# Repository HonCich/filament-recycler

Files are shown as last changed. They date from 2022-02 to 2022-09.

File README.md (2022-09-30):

# filament-recyclator
 
## About project
 The goal of the work is design and implementation of a machine for production and recyclation of 3D printing material for FDM 3D printers (filament). The emphasis is put on the simplicity of the resulting device and the ease of its production process.

 I started working on this project at the end of summer 2021 with great help from Ing. Martin Ptáček. It started as my project for Středoškolská odborná činnost, which is science competetion held in the Czech Republic. After this competetion I decided to continue and further upgrade this machine.

 At this moment project contains working designs of filament extruder, filament puller, electronics board and software.

## 3D models
[Extruder 3D model](https://cad.onshape.com/documents/50d4ffc71355bbf60bf18542/w/1bb6894ef7bc64ec395a8974/e/ffa39023716e79eba0ffd74a)

[Gearbox 3D model](https://cad.onshape.com/documents/cd74832d7d2c633c7039baa6/w/958712d359a12f9b1e2d2bfe/e/a4a0fd0a7c25512e608e8250)

[Filament puller 3D model](https://cad.onshape.com/documents/47426692b6b663d8016df0e7/w/ed22a120c506776f4e319dcb/e/ad41a19a2c0e068ddb01ab12)

## Licence
* Contents of this repository except *software* folder are shared under [Attribution-NonCommercial-ShareAlike 4.0 International (CC BY-NC-SA 4.0)](https://creativecommons.org/licenses/by-nc-sa/4.0/) licence.
* Contents of *software* folder are shared under [GNU Lesser General Public License v3.0](https://www.gnu.org/licenses/lgpl-3.0.en.html) licence.

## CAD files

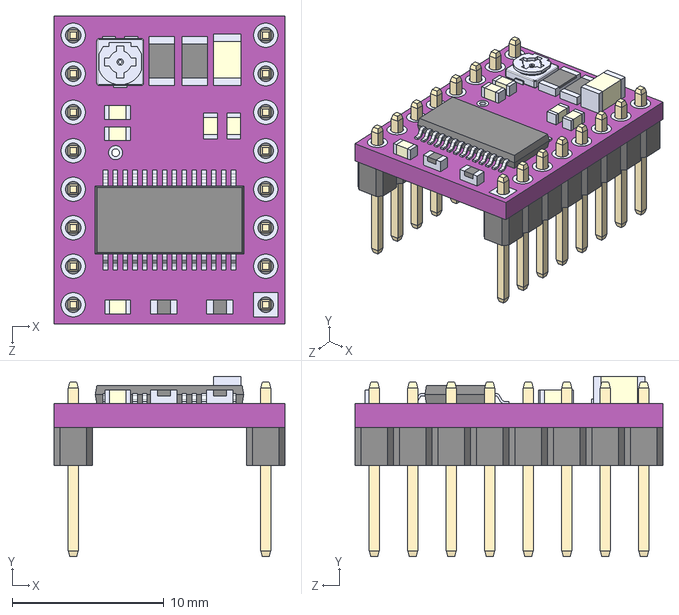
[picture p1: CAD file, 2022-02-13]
main_board/DRV8825 STEPPER MOTOR DRIVER CARRIER--3DModel-STEP-1.STEP
15.2 x 11.9 x 20.3 mm

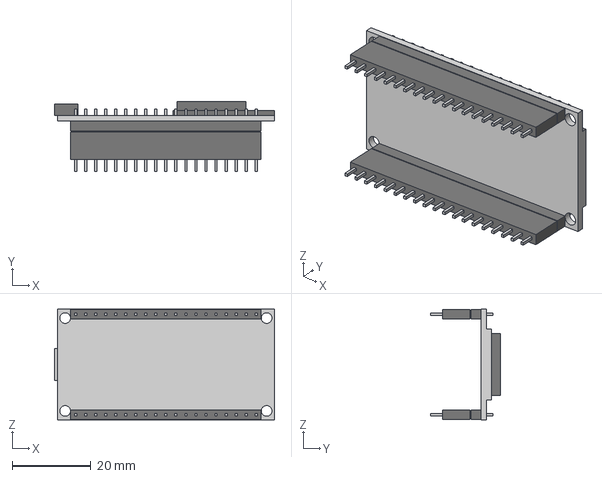
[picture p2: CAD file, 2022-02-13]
main_board/ESP32_DevKitC v2.step
55.7 x 17.6 x 28.0 mm

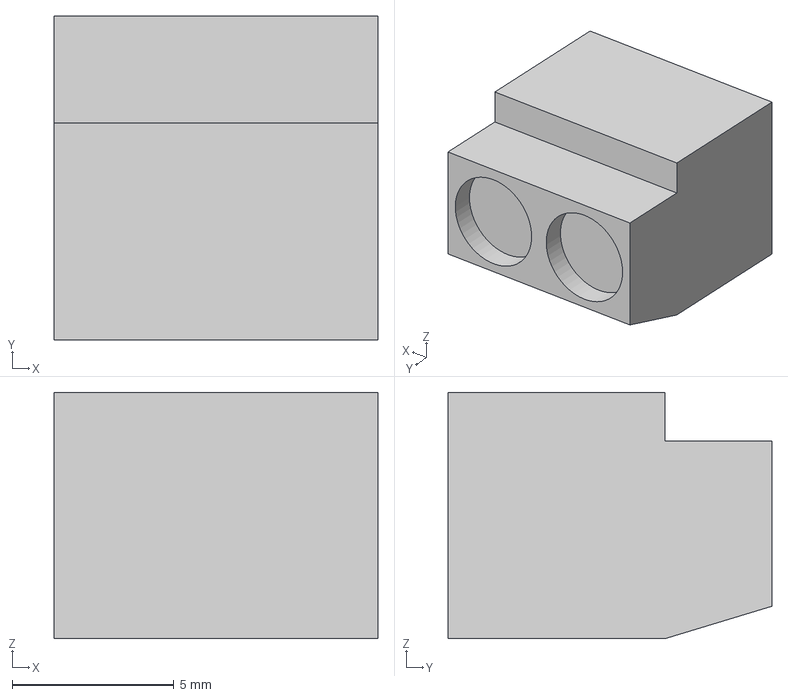
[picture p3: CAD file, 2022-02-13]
main_board/Screw_terminal_2x5.08 v2.step
10.0 x 10.0 x 7.60 mm

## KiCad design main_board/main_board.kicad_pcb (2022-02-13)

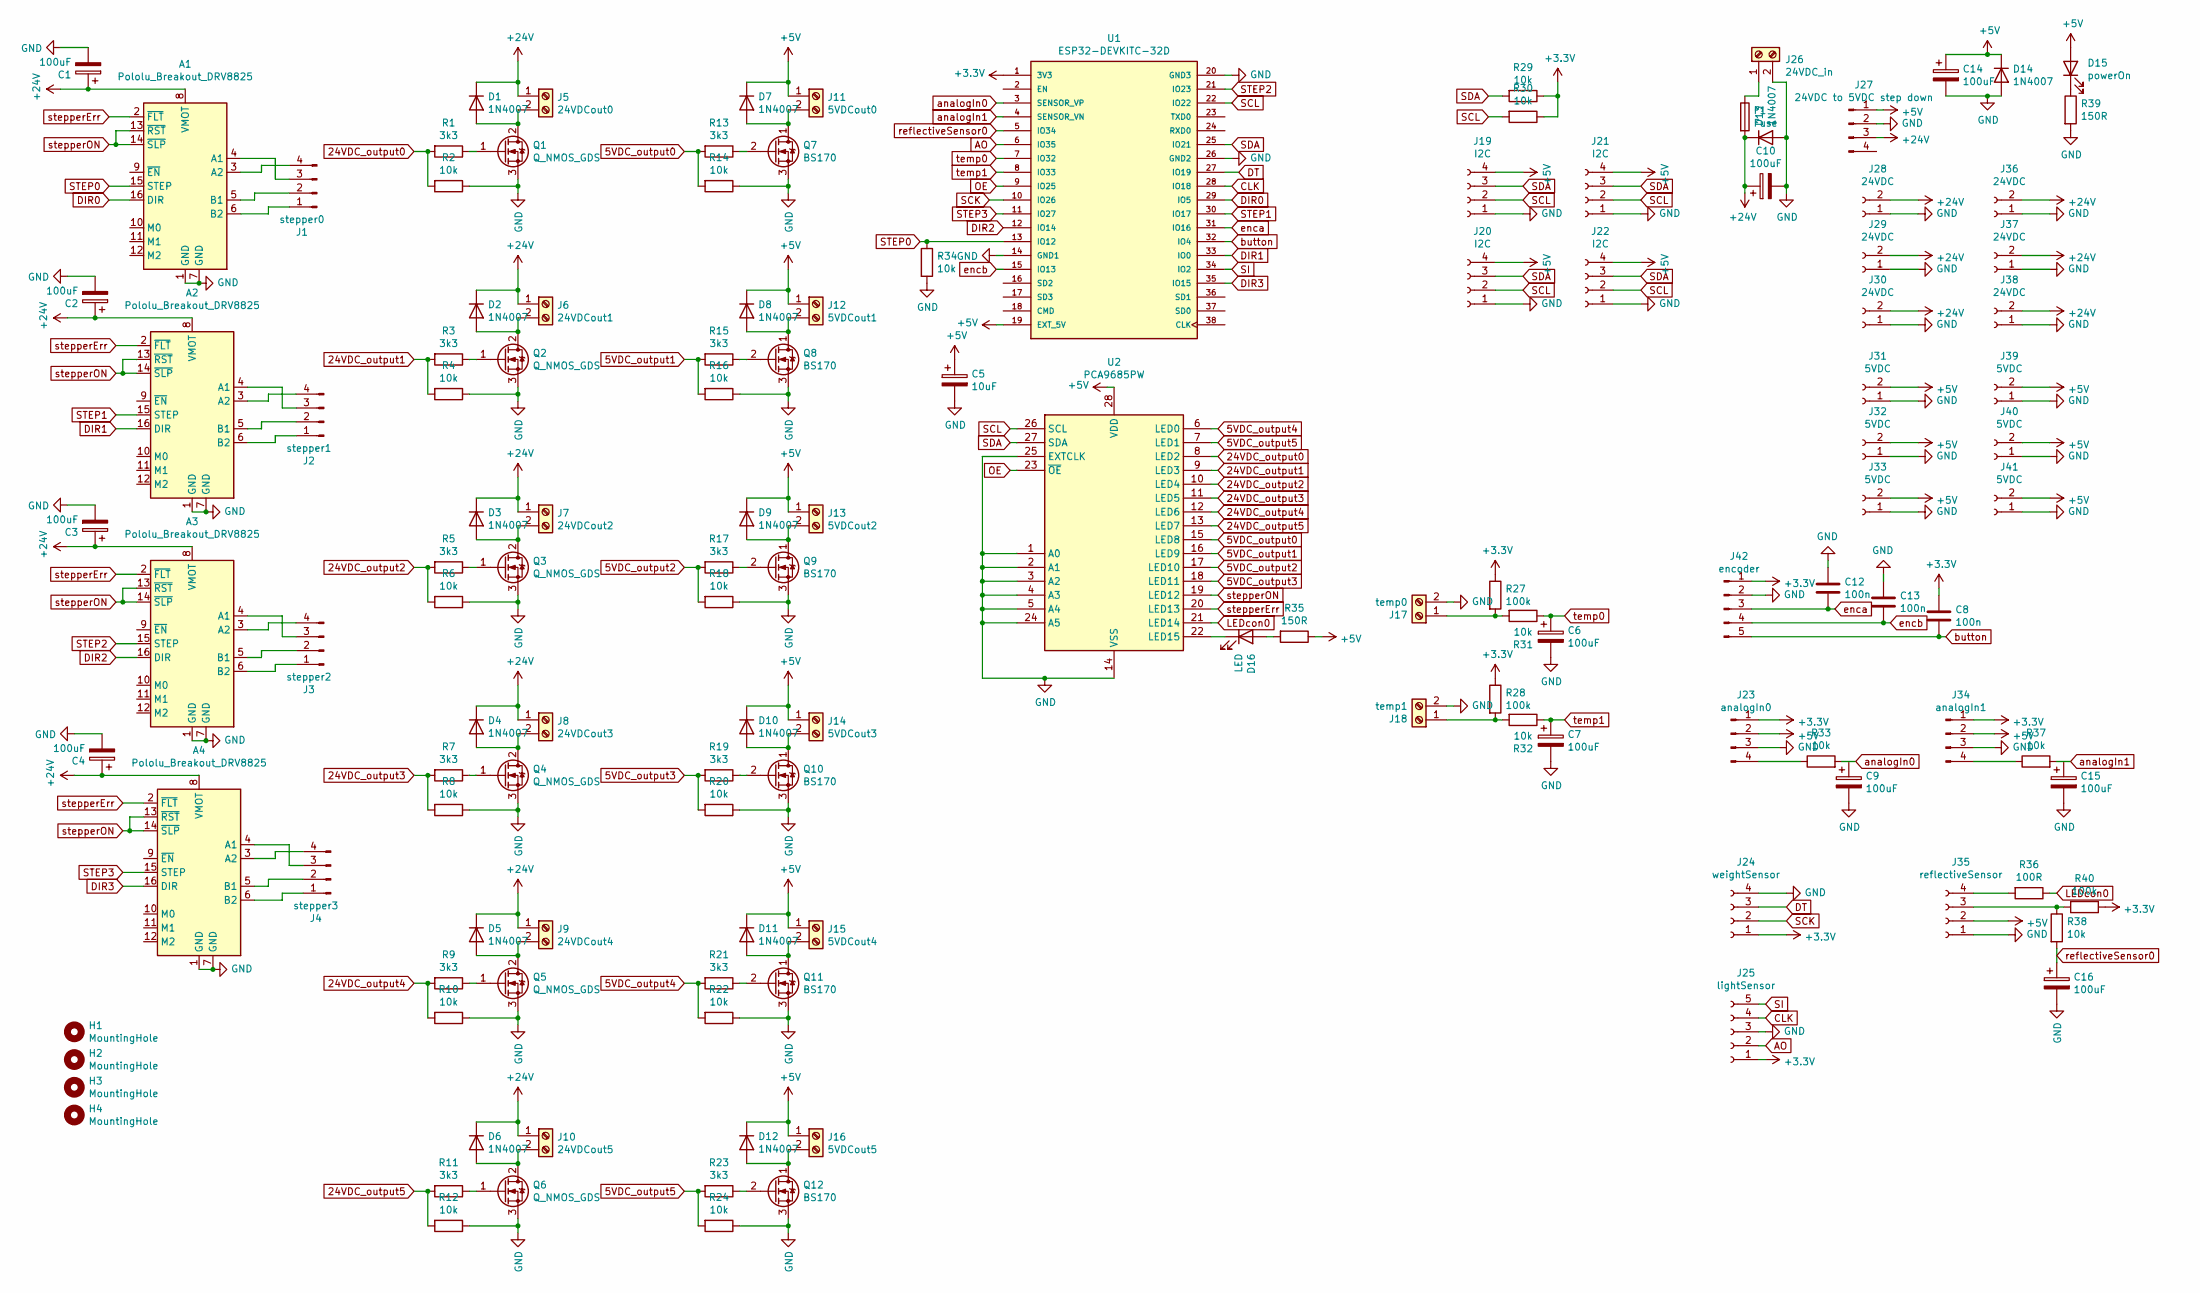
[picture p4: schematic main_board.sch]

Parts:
A1, A2, A3, A4: Pololu_Breakout_DRV8825; Pololu_Breakout-16_15.2x20.3mm
C1, C2, C3, C4, C6, C7, C9, C10, C14, C15, C16: 100uF; CP_Radial_D6.3mm_P2.50mm
C5: 10uF; CP_Radial_D6.3mm_P2.50mm
C8, C12, C13: 100n; C_1206_3216Metric_Pad1.33x1.80mm_HandSolder
D1, D2, D3, D4, D5, D6, D7, D8, D9, D10, D11, D12, D13, D14: 1N4007; D_DO-15_P2.54mm_Vertical_AnodeUp
D15: powerOn; LED_D3.0mm
D16: LED; LED_D3.0mm
F1: Fuse; Fuseholder_Cylinder-5x20mm_Schurter_0031_8201_Horizontal_Op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
H1, H2, H3, H4: MountingHole; MountingHole_3.2mm_M3
J1: stepper0; PinHeader_1x04_P2.54mm_Vertical
J2: stepper1; PinHeader_1x04_P2.54mm_Vertical
J3: stepper2; PinHeader_1x04_P2.54mm_Vertical
J4: stepper3; PinHeader_1x04_P2.54mm_Vertical
J5: 24VDCout0; TerminalBlock_bornier-2_P5.08mm
J6: 24VDCout1; TerminalBlock_bornier-2_P5.08mm
J7: 24VDCout2; TerminalBlock_bornier-2_P5.08mm
J8: 24VDCout3; TerminalBlock_bornier-2_P5.08mm
J9: 24VDCout4; TerminalBlock_bornier-2_P5.08mm
J10: 24VDCout5; TerminalBlock_bornier-2_P5.08mm
J11: 5VDCout0; TerminalBlock_bornier-2_P5.08mm
J12: 5VDCout1; TerminalBlock_bornier-2_P5.08mm
J13: 5VDCout2; TerminalBlock_bornier-2_P5.08mm
J14: 5VDCout3; TerminalBlock_bornier-2_P5.08mm
J15: 5VDCout4; TerminalBlock_bornier-2_P5.08mm
J16: 5VDCout5; TerminalBlock_bornier-2_P5.08mm
J17: temp0; TerminalBlock_bornier-2_P5.08mm
J18: temp1; TerminalBlock_bornier-2_P5.08mm
J19, J20, J21, J22: I2C; PinHeader_1x04_P2.54mm_Vertical
J23: analogIn0; PinHeader_1x04_P2.54mm_Vertical
J24: weightSensor; PinHeader_1x04_P2.54mm_Vertical
J25: lightSensor; PinHeader_1x05_P2.54mm_Vertical
J26: 24VDC_in; TerminalBlock_bornier-2_P5.08mm
J27: 24VDC to 5VDC step down; PinHeader_1x04_P2.54mm_Vertical
J28, J29, J30, J36, J37, J38: 24VDC; PinHeader_1x02_P2.54mm_Vertical
J31, J32, J33, J39, J40, J41: 5VDC; PinHeader_1x02_P2.54mm_Vertical
J34: analogIn1; PinHeader_1x04_P2.54mm_Vertical
J35: reflectiveSensor; PinHeader_1x04_P2.54mm_Vertical
J42: encoder; PinHeader_1x05_P2.54mm_Vertical
Q1, Q2, Q3, Q4, Q5, Q6: Q_NMOS_GDS; TO-220-3_Vertical
Q7, Q8, Q9, Q10, Q11, Q12: BS170; TO-92_Inline_Wide
R1, R3, R5, R7, R9, R11, R13, R15, R17, R19, R21, R23: 3k3; R_1206_3216Metric_Pad1.30x1.75mm_HandSolder
R2, R4, R6, R8, R10, R12, R14, R16, R18, R20, R22, R24, R29, R30, R31, R32, R33, R34, R37, R38: 10k; R_1206_3216Metric_Pad1.30x1.75mm_HandSolder
R27, R28, R40: 100k; R_1206_3216Metric_Pad1.30x1.75mm_HandSolder
R35, R39: 150R; R_1206_3216Metric_Pad1.30x1.75mm_HandSolder
R36: 100R; R_1206_3216Metric_Pad1.30x1.75mm_HandSolder
U1: ESP32-DEVKITC-32D; MODULE_ESP32-DEVKITC-32D; PARTREV 4
U2: PCA9685PW; TSSOP-28_4.4x9.7mm_P0.65mm

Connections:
5VDC_output0: R13.2, R14.2, U2.15 (LED8)
5VDC_output1: R15.2, R16.2, U2.16 (LED9)
5VDC_output2: R17.2, R18.2, U2.17 (LED10)
5VDC_output3: R19.2, R20.2, U2.18 (LED11)
5VDC_output4: R21.2, R22.2, U2.6 (LED0)
5VDC_output5: R23.2, R24.2, U2.7 (LED1)
24VDC_output0: R1.2, R2.2, U2.8 (LED2)
24VDC_output1: R3.2, R4.2, U2.9 (LED3)
24VDC_output2: R5.2, R6.2, U2.10 (LED4)
24VDC_output3: R7.2, R8.2, U2.11 (LED5)
24VDC_output4: R9.2, R10.2, U2.12 (LED6)
24VDC_output5: R11.2, R12.2, U2.13 (LED7)
+3V3: C8.2, J23.1, J24.1, J25.1, J34.1, J42.1, R27.1, R28.1, R29.1, R30.1, R40.1, U1.1 (3V3)
+5V: C5.1, C14.1, D7.1 (K), D8.1 (K), D9.1 (K), D10.1 (K), D11.1 (K), D12.1 (K), D14.1 (K), D15.2 (A), J11.1, J12.1, J13.1, J14.1, J15.1, J16.1, J19.4, J20.4, J21.4, J22.4, J23.2, J27.1, J31.2, J32.2, J33.2, J34.2, J35.2, J39.2, J40.2, J41.2, R35.1, U1.19 (EXT_5V), U2.28 (VDD)
+24V: A1.8 (VMOT), A2.8 (VMOT), A3.8 (VMOT), A4.8 (VMOT), C1.1, C2.1, C3.1, C4.1, C10.1, D1.1 (K), D2.1 (K), D3.1 (K), D4.1 (K), D5.1 (K), D6.1 (K), D13.1 (K), F1.2, J5.1, J6.1, J7.1, J8.1, J9.1, J10.1, J27.3, J28.2, J29.2, J30.2, J36.2, J37.2, J38.2
AO: J25.2, U1.6 (IO35)
CLK: J25.4, U1.28 (IO18)
DIR0: A1.16 (DIR), U1.29 (IO5)
DIR1: A2.16 (DIR), U1.33 (IO0)
DIR2: A3.16 (DIR), U1.12 (IO14)
DIR3: A4.16 (DIR), U1.35 (IO15)
DT: J24.3, U1.27 (IO19)
GND: A1.1 (GND), A1.7 (GND), A2.1 (GND), A2.7 (GND), A3.1 (GND), A3.7 (GND), A4.1 (GND), A4.7 (GND), C1.2, C2.2, C3.2, C4.2, C5.2, C6.2, C7.2, C9.2, C10.2, C12.2, C13.2, C14.2, C15.2, C16.2, D13.2 (A), D14.2 (A), J17.2, J18.2, J19.1, J20.1, J21.1, J22.1, J23.3, J24.4, J25.3, J26.2, J27.2, J28.1, J29.1, J30.1, J31.1, J32.1, J33.1, J34.3, J35.1, J36.1, J37.1, J38.1, J39.1, J40.1, J41.1, J42.2, Q1.3 (S), Q2.3 (S), Q3.3 (S), Q4.3 (S), Q5.3 (S), Q6.3 (S), Q7.3 (S), Q8.3 (S), Q9.3 (S), Q10.3 (S), Q11.3 (S), Q12.3 (S), R2.1, R4.1, R6.1, R8.1, R10.1, R12.1, R14.1, R16.1, R18.1, R20.1, R22.1, R24.1, R34.2, R39.2, U1.14 (GND1), U1.20 (GND3), U1.26 (GND2), U2.1 (A0), U2.2 (A1), U2.3 (A2), U2.4 (A3), U2.5 (A4), U2.14 (VSS), U2.24 (A5), U2.25 (EXTCLK)
LEDcon0: R36.1, U2.21 (LED14)
unnamed: A1.3 (A2), J1.4
unnamed: A1.4 (A1), J1.3
unnamed: A1.5 (B1), J1.2
unnamed: A1.6 (B2), J1.1
unnamed: A2.3 (A2), J2.4
unnamed: A2.4 (A1), J2.3
unnamed: A2.5 (B1), J2.2
unnamed: A2.6 (B2), J2.1
unnamed: A3.3 (A2), J3.4
unnamed: A3.4 (A1), J3.3
unnamed: A3.5 (B1), J3.2
unnamed: A3.6 (B2), J3.1
unnamed: A4.3 (A2), J4.4
unnamed: A4.4 (A1), J4.3
unnamed: A4.5 (B1), J4.2
unnamed: A4.6 (B2), J4.1
unnamed: D1.2 (A), J5.2, Q1.2 (D)
unnamed: D2.2 (A), J6.2, Q2.2 (D)
unnamed: D3.2 (A), J7.2, Q3.2 (D)
unnamed: D4.2 (A), J8.2, Q4.2 (D)
unnamed: D5.2 (A), J9.2, Q5.2 (D)
unnamed: D6.2 (A), J10.2, Q6.2 (D)
unnamed: D7.2 (A), J11.2, Q7.1 (D)
unnamed: D8.2 (A), J12.2, Q8.1 (D)
unnamed: D9.2 (A), J13.2, Q9.1 (D)
unnamed: D10.2 (A), J14.2, Q10.1 (D)
unnamed: D11.2 (A), J15.2, Q11.1 (D)
unnamed: D12.2 (A), J16.2, Q12.1 (D)
unnamed: D15.1 (K), R39.1
unnamed: D16.1 (K), U2.22 (LED15)
unnamed: D16.2 (A), R35.2
unnamed: F1.1, J26.1
unnamed: J17.1, R27.2, R31.2
unnamed: J18.1, R28.2, R32.2
unnamed: J23.4, R33.1
unnamed: J34.4, R37.1
unnamed: J35.3, R38.1, R40.2
unnamed: J35.4, R36.2
unnamed: Q1.1 (G), R1.1
unnamed: Q2.1 (G), R3.1
unnamed: Q3.1 (G), R5.1
unnamed: Q4.1 (G), R7.1
unnamed: Q5.1 (G), R9.1
unnamed: Q6.1 (G), R11.1
unnamed: Q7.2 (G), R13.1
unnamed: Q8.2 (G), R15.1
unnamed: Q9.2 (G), R17.1
unnamed: Q10.2 (G), R19.1
unnamed: Q11.2 (G), R21.1
unnamed: Q12.2 (G), R23.1
OE: U1.9 (IO25), U2.23 (~OE)
SCK: J24.2, U1.10 (IO26)
SCL: J19.2, J20.2, J21.2, J22.2, R30.2, U1.22 (IO22), U2.26 (SCL)
SDA: J19.3, J20.3, J21.3, J22.3, R29.2, U1.25 (IO21), U2.27 (SDA)
SI: J25.5, U1.34 (IO2)
STEP0: A1.15 (STEP), R34.1, U1.13 (IO12)
STEP1: A2.15 (STEP), U1.30 (IO17)
STEP2: A3.15 (STEP), U1.21 (IO23)
STEP3: A4.15 (STEP), U1.11 (IO27)
analogIn0: R33.2, U1.3 (SENSOR_VP)
analogIn1: R37.2, U1.4 (SENSOR_VN)
button: C8.1, J42.5, U1.32 (IO4)
enca: C12.1, J42.3, U1.31 (IO16)
encb: C13.1, J42.4, U1.15 (IO13)
reflectiveSensor0: C16.1, R38.2, U1.5 (IO34)
stepperErr: A1.2 (~FLT), A2.2 (~FLT), A3.2 (~FLT), A4.2 (~FLT), U2.20 (LED13)
stepperON: A1.13 (~RST), A1.14 (~SLP), A2.13 (~RST), A2.14 (~SLP), A3.13 (~RST), A3.14 (~SLP), A4.13 (~RST), A4.14 (~SLP), U2.19 (LED12)
temp0: C6.1, R31.1, U1.7 (IO32)
temp1: C7.1, R32.1, U1.8 (IO33)

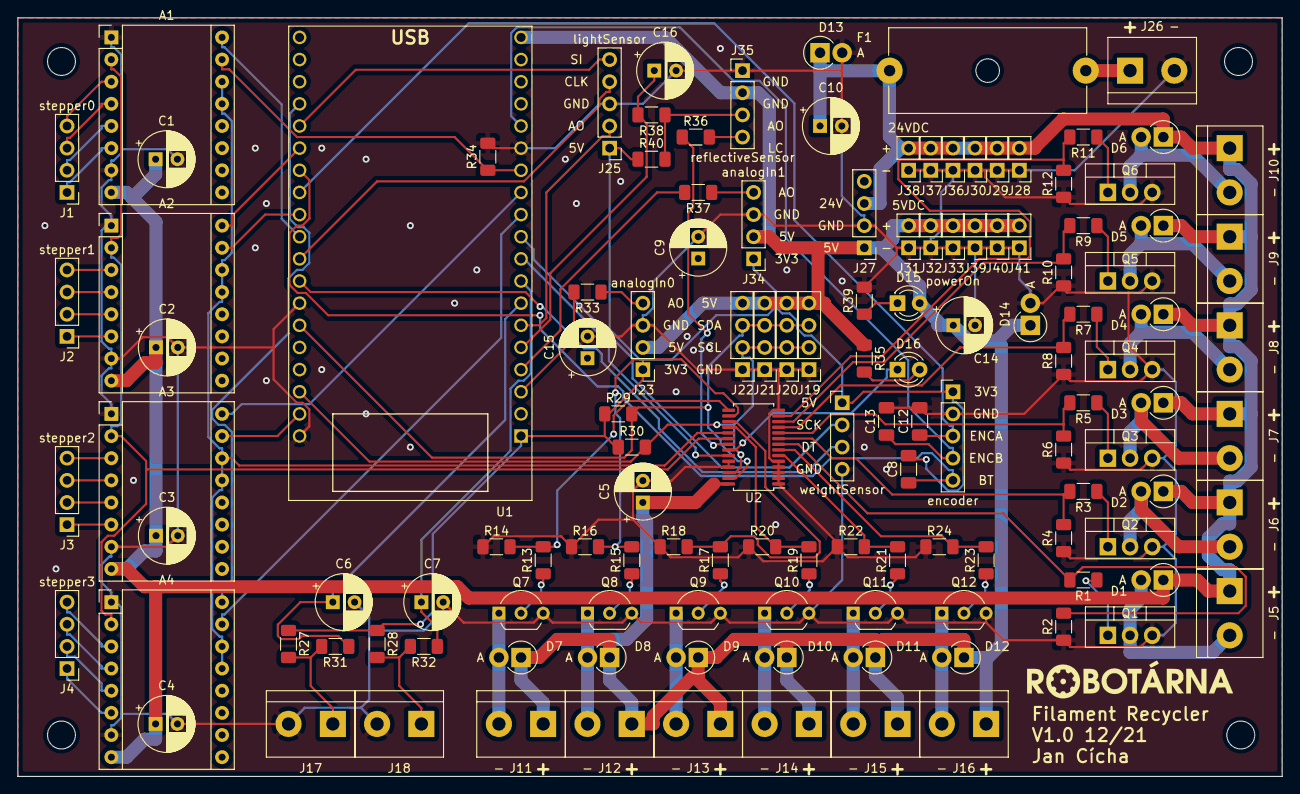
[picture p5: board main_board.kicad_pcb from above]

Board: 2 copper layers, 145.0 x 87.0 mm, 134 parts (0 on the bottom side), 93 nets.

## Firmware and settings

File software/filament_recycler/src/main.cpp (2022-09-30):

#include <Arduino.h>
#include <HardwareSerial.h>
#include "Wire.h"
#include "PCA9685.h"
#include "HX711.h"
#include "AccelStepper.h"
#include "MultiStepper.h"


const uint8_t reflectivesensor0 = 34;
const uint8_t PCA_OE = 25;
const uint8_t stepperON = 12;
const uint8_t LEDsign = 15;
const uint8_t step0 = 12;
const uint8_t dir0 = 5;
const uint8_t step1 = 17;
const uint8_t dir1 = 0;
char tempPin[2]={32,33};
char fiveVPin[6]={8,9,10,11,0,1};
char twentyFourVPin[6]={2,3,4,5,6,7};

int prevTime = 0;

const float c1 = 0.0007157730988481782;
const float c2 = 0.0002145860245372531;
const float c3 = 1.0991444718982721e-7;

PCA9685 PCA(0x70);
AccelStepper stepper0(AccelStepper::DRIVER, step0, dir0);
AccelStepper stepper1(AccelStepper::DRIVER, step1, dir1);

void outputEnable (bool enable);
void fiveVDrive (uint8_t output, int value);
void twentyFourVDrive (uint8_t output, int value);
int reflectiveRead ();
float tempRead (uint8_t temp);

void outputEnable (bool enable)
{
    digitalWrite(PCA_OE, !enable);
    PCA.digitalWrite(stepperON,enable);
    PCA.digitalWrite(LEDsign,enable);
}

void fiveVDrive (uint8_t output, int value)
{
  PCA.setPWM(fiveVPin[output],0+value*40.95);
}

void twentyFourVDrive (uint8_t output, int value)
{
  PCA.setPWM(twentyFourVPin[output],0+value*40.95);
}

int reflectiveRead ()
{
  PCA.setON(14);
  return analogRead(reflectivesensor0);
}

float tempRead (uint8_t temp)
{
  float R,T,logR;
  R = 100000 / (4095.0 / analogRead(tempPin[temp]) - 1.0);
  logR = log(R);
  T = (1 / (c1 + c2 * logR + c3 * logR * logR * logR)) - 273.15;
  Serial.println(T);
  return(T);
}

void setup() {
  // put your setup code here, to run once:
  Serial.begin(9600);
  Wire.begin(); 
  PCA.begin();

  outputEnable(1);
  stepper0.setAcceleration(200.0);
  stepper0.setMaxSpeed(1000);
  stepper0.setSpeed(200);
  stepper1.setAcceleration(200.0);
  stepper1.setMaxSpeed(1000);
  stepper1.setSpeed(2);

  twentyFourVDrive(0,80);
  twentyFourVDrive(1,80);
  /*while (tempRead(0)<260)
  {
    delay(1000);
  }
  
  prevTime = millis();*/
}


void loop() {
  // put your main code here, to run repeatedly
  /*if (millis()-prevTime>=1000)
  {
    if(tempRead(0)<300)
    {
      twentyFourVDrive(0,100);
      twentyFourVDrive(1,100);
    }
    else
    {
      twentyFourVDrive(0,0);
      twentyFourVDrive(1,0);
    }
    prevTime=millis();
  }*/
  
stepper0.runSpeed();
stepper1.runSpeed();
}

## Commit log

2021-02-03 started main board schematic
    [main_board.kicad_pcb, main_board.sch]
2021-04-22 started board
    [main_board.kicad_pcb]
2021-11-24 added parts to scheme
    [main_board.kicad_pcb, main_board.sch]
2021-11-29 schematic update
    [main_board.sch]
2021-11-30 footprints assigned
    [main_board.sch]
2021-12-05 PCB started
    [main_board.kicad_pcb, main_board.sch]
2021-12-06 PCB v1
    [main_board.kicad_pcb, main_board.sch]
2021-12-07 PCB changes
    [main_board.kicad_pcb, main_board.sch]
2021-12-08 routs added
    [main_board.kicad_pcb]
2021-12-08 making pcb smaller
    [main_board.kicad_pcb]
2021-12-09 PCB update
    [main_board.kicad_pcb]
2021-12-09 added routs
    [main_board.kicad_pcb, main_board.sch]
2021-12-12 added gnd zones
    [main_board.kicad_pcb, main_board.sch]
2021-12-13 part names moved
    [main_board.kicad_pcb]
2021-12-13 part numbers added
    [main_board.kicad_pcb, main_board.sch]
2021-12-14 GND zones added
    [main_board.kicad_pcb, main_board.sch]
2021-12-14 GND zone update
    [main_board.kicad_pcb]
2021-12-14 production files generated
    [main_board-B_Cu.gbl, main_board-B_Mask.gbs, main_board-B_Paste.gbp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]
2021-12-14 ADC 2 unused
    [main_board-B_Cu.gbl, main_board-B_Mask.gbs, main_board-B_Paste.gbp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]
2021-12-15 problems fix
    [main_board.kicad_pcb, main_board.sch]
2021-12-15 bug fix
    [main_board.kicad_pcb]
2022-01-28 motor problem
2022-02-13 problem s topenim
    [DRV8825 STEPPER MOTOR DRIVER CARRIER--3DModel-STEP-1.STEP, ESP32_DevKitC v2.step, Screw_terminal_2x5.08 v2.step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]
